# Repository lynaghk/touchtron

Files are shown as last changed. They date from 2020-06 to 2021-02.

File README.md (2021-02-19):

# Touchtron

Misc. experiments with Rust + USB, Kevin making a touchpad.

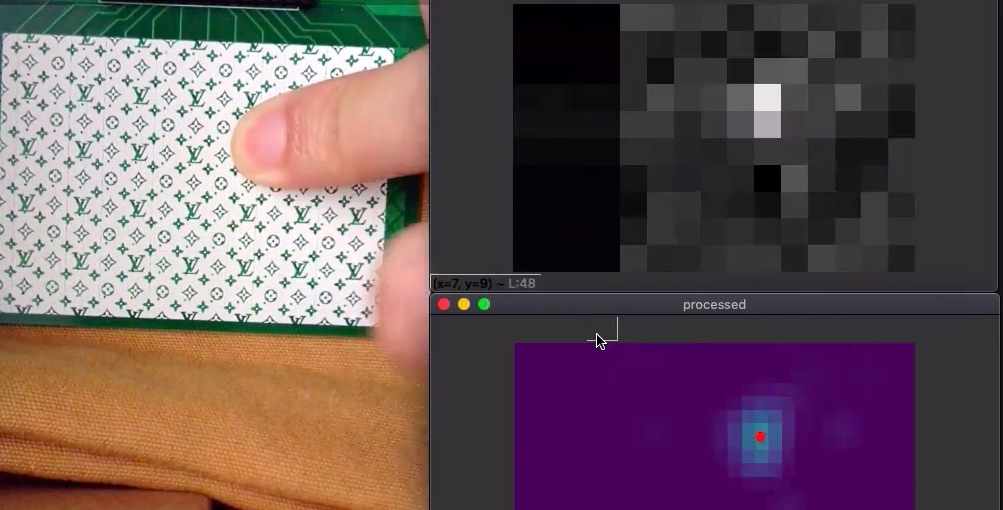
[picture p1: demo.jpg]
A finger on a touchpad; data analysis windows


See [background + video demo](https://kevinlynagh.com/touchpad/).

The [firmware-f0](firmware-f0/) is the fully-baked code running on the PCB ([schematic PDF](pcb/submitted_2020_05_26/touchtron.pdf)).

This was a personal research project that I'm sharing in case it's helpful for others playing with touchpads, embedded Rust, etc.

## MacOS Setup 

```
#for stm32f0 (kevin custom board)
rustup target add thumbv6m-none-eabi 

#for stm32f1 (blue pill board)
rustup target add thumbv7m-none-eabi

pip install numpy matplotlib scipy opencv-python

pip install pyusb
brew install libusb 
```

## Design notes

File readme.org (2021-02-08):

# Touchtron

Misc. experiments with Rust + USB, Kevin making a touchpad.

* MacOS Setup 

#for stm32f0 (kevin custom board)
rustup target add thumbv6m-none-eabi 

#for stm32f1 (blue pill board)
rustup target add thumbv7m-none-eabi

pip install numpy matplotlib scipy opencv-python

pip install pyusb
brew install libusb 

MIDI stuff:
virtual keyboard for generating events: https://flit.github.io/projects/midikeys/
monitoring MIDI events on the system: https://www.snoize.com/MIDIMonitor/

* misc research / notes
https://jan.rychter.com/fingerworks-touchstream-kbd

https://bill.harding.blog/tag/touchpad/

clever in software debouncing: https://github.com/dbrgn/debouncr/
** lcsc stm32 parts with lots of channels
| part          | adcs |     CHs | basic? | pins | cost | note                        |
| STM32F303RCT6 |    4 | 22 real |        |   64 | 2.94 |                             |
| STM32F103VBT6 |    2 |      16 | x      |  100 | 1.99 |                             |
| STM32L073V8T6 |    1 |      16 |        |  100 | 1.96 | crystalless usb             |
| STM32F407VGT6 |    3 |     ... |        |      | 4.33 | adcs share same 16 channels |
| STM32L151C8T6 |    1 |      24 | x      |   48 | 1.85 |                             |
| STM32L152RBT6 |    1 |      24 |        |   64 | 2.90 |                             |
| STM32F030C8T6 |    1 |      16 | x      |   48 | 0.79 | no usb                      |
| STM32G031C6T6 |    1 |      16 |        |   48 | 1.68 |                             |
** other ways to get more rows/columns:

https://electronics.stackexchange.com/questions/293809/connecting-multiple-signals-to-adc

CD4051B is $0.20 JLC part that demuxes 8 channels to 1. filed under "4000" series rather than "multiplexers" = (
74HC4051D $0.12e JLC 8-to-1 demux

need op-amp to buffer high-impedence touchpad sensor signal?

STM32F070F6 

$0.0015/joint

** Mac raw gesture data
from https://ia801404.us.archive.org/15/items/2009-03-28-steike-code-macbook-multitouch/2009-03-28%20%28archived%202014-06-17%29%20-%20steike%20macbook%20multitouch.html
via Vivek

Here's code to read the raw gesture data from a MacBook trackpad.

[Update: if you're on a MacBook with Java enabled, you can try the demo applet]

If you use this to make something fun, please let me know and I'll post it here...

Notes about the fields of the Finger struct:

identifier
    Persistent identifier for each touch -- each "finger" may move around the Fingers[] array, but this will remain the same. 
normalized.pos.x
    Current position, from [0..1] 
size
    Close to zero if you're barely touching the touch pad 
angle, majorAxis, minorAxis
    Describes the ellipsoid of your finger. Yes, you can track rotation of a single finger! 

#include <math.h>
#include <unistd.h>
#include <CoreFoundation/CoreFoundation.h>

typedef struct { float x,y; } mtPoint;
typedef struct { mtPoint pos,vel; } mtReadout;

typedef struct {
  int frame;
  double timestamp;
  int identifier, state, foo3, foo4;
  mtReadout normalized;
  float size;
  int zero1;
  float angle, majorAxis, minorAxis; // ellipsoid
  mtReadout mm;
  int zero2[2];
  float unk2;
} Finger;

typedef void *MTDeviceRef;
typedef int (*MTContactCallbackFunction)(int,Finger*,int,double,int);

MTDeviceRef MTDeviceCreateDefault();
void MTRegisterContactFrameCallback(MTDeviceRef, MTContactCallbackFunction);
void MTDeviceStart(MTDeviceRef, int); // thanks comex

int callback(int device, Finger *data, int nFingers, double timestamp, int frame) {
  for (int i=0; i<nFingers; i++) {
    Finger *f = &data[i];
    printf("Frame %7d: Angle %6.2f, ellipse %6.3f x%6.3f; "
    	   "position (%6.3f,%6.3f) vel (%6.3f,%6.3f) "
    	   "ID %d, state %d [%d %d?] size %6.3f, %6.3f?\n",
	   f->frame,
	   f->angle * 90 / atan2(1,0),
	   f->majorAxis,
	   f->minorAxis,
	   f->normalized.pos.x,
	   f->normalized.pos.y,
	   f->normalized.vel.x,
	   f->normalized.vel.y,
	   f->identifier, f->state, f->foo3, f->foo4,
	   f->size, f->unk2);
  }
  printf("\n");
  return 0;
}

int main() {
  MTDeviceRef dev = MTDeviceCreateDefault();
  MTRegisterContactFrameCallback(dev, callback);
  MTDeviceStart(dev, 0);
  printf("Ctrl-C to abort\n");
  sleep(-1);
  return 0;
}

run: test
	./test
test: test.m
	gcc -F/System/Library/PrivateFrameworks -framework MultitouchSupport $^ -o $@ -std=c99

Comments
Could you please explain how you go about compiling this code. I tried including the MultitouchSupport framework under PrivateFrameworks and I get "ld: framework not found MultitouchSupport"
— Al 2009-05-27
[Ah, I hadn't tried compiling it in Xcode. It appears to be silently prepending all paths with /Developer/SDKs/MacOS10.xxx/. You need to change the 'Base SDK' setting (under Project settings) from 'MacOS 10.whatever' to 'Current OS'.]
Excelletn stuff. Al, the sendo text is a make file, just put it into 'Makefile' in the same dir and type make. I am wrapping the code in a Java Wrapper, but im only geting the MT debug init message, not any MT events. I guess its somethine todo with threading (e.g. main thread) and perhaps how the java binary is (or not) dynamically binding with the Framework(s). I'm really not sure asthis is my 1st trip into native MacOS system dev/integration... (but im well seasoned elsewhere :)
— Wayne 2009-05-27
Excellent! We just built an external for MaxMSP around your code. We'd like to release it under the GNU GPL 2.0, if that is fine by you? [binary / source]
— Max & Michael 2009-06-02
[Brilliant! Max/MSP looks awesome; I'll have to play with it as soon as I'm done moving.]
Hi, Greetings from the maker of the multitouch Fingerworks NumPad Max/MSP external I salute you! The circle is now complete.
— jusu 2009-06-08
Great stuff! The only problem is that when I play with the gestures, I tend to trigger Expose. Any idea how to deactivate it (at least the three- and four-finger gestures that aren't really all that useful to begin with)?
— Robert 2009-07-02
[For testing purposes, I just used killall -STOP Dock. This also disables Cmd-Tab and other system hotkeys; killall -CONT Dock to bring it back.]
Cool!

btw, can I use the code inside my own project? I'm gonna release the project under GPL because I use another library that uses GPL. By doing so, it means, I also release your code under GPL.

I make a TUIO wrapper over your code. So the multi-touch events from the touchpad will be forwarded as TUIO messages. These later can be used by any TUIO-enabled multi-touch application.
— Anonymous 2009-08-08
Very cool stuff! I build a TUIO wrapper around your code (http://github.com/fajran/tongseng/tree/master). In case you don't know, TUIO is a protocol that is usually used to create a multitouch application. More information here http://www.tuio.org/
— Fajran 2009-08-15
To get this to work on Snow Leopard/64-bit/in a more complicated program, I had to change MTDeviceRef to a long and add a second int argument to MTDeviceStart; otherwise, I would get crashes and/or no events.
— comex 2009-08-30
[I have updated the code. Thanks!]
Perhaps I am too foolish or new to make this work, but on Snow Leopard 10.6.1 when I put the source in 'test.m' and have a Makefile it makes, but I get a segmentation fault when I run it. fprintf tells me that the fault happens during

MTRegisterContactFrameCallback(dev, callback);

I have also tried copying the MultitouchSupport.framework folder in to the folder I'm working in, and to no avail.

Is this different in 10.6 then? Am I missing something?
— Jonathan 2009-09-21
[This was preemptively answered by comex, but his comment was stuck in the 
* Log
To try:

+ paper's lowest SNR = 57 +/- 20; single touch SNR around 70 +/- 10; ratio of 15 is min required.
+ "We observed that thicker top insulators (more than 400 um) will render the interface unusable." (soldermask thickness ~ 25 um; silkscreen is similar.)

** 2020 June 24 measurement

Using Hackerspace's Hantek DSO8060 portable scope to measure touchpad.

Measuring output ch 6, input ch 4

4ms period for a single pin --- this is the column scan.
Zooming in it reads 10MHz signal for the PWM.

PWM peak to peak voltage is 1.9V
Untouched 220mV
Touched 0.9--1.1V but the signal floats all over the place (varying DC offset)
However, it's clearly coupled to the PWM output signal

At period = 48 (1MHz):

PWM peak to peak is 3V
untouched 260mV
touched 0.8--1V, also floating everywhere. why?

hmm, maybe the floating was scope probe error.
Going back to 9.6MHz signal (period = 4; must be an extra cycle in there somewhere.) I see

1.9 PWM peak to peak
220 mV untouched
550 mV light touch

sometimes the floor wiggles around, other times I can cause big amplitude increase from coupling but the floor stays constant.
I think the floor movement is noise from my finger
maybe I need a high pass filter to get rid of it?

** 2020 June 23 Python analysis

Matplotlib code struggles to update heatmap quickly.
Perf timing in code suggests it can run at 160 FPS but it's obviously not running that fast.
Scaling the window makes it even laggier.

Tried upgrading to python3.8, changing backend to qt5. no dice.

** 2020 June 22 ADC overrun
I keep getting overrun errors from the ADC, even when the interrupt just reads the register and does nothing else.
Maybe this read is getting optimized away?
Nah, must be timing because even if the interrupt runs only:

    self.adc.rb.isr.modify(|_, w| w.eoc().clear());

I still get overrun errors
This doesn't make sense, is the ADC really sampling that fast?

----

with no pwm signal, noise is around 8--9.
50--90 with a finger.
With a single PWM, noise is around 80--100.

** 2020 June 21 Manual ADC usage

ADC can be set to scan through all channels in order.
Lets just do this continously, collecting values in a rolling buffer or something.
Then when USB polls we can send all collected data to the host

enable channels in ADC_CHSELR
ADC_CFGR1.cont = 1

set EOCIE flag so interrupt is generated after each sample taken
clear EOC flag and transfer result to new buffer

watch OVR flag for overrun. this shouldn't happen in normal operation if interrupt handler is fast enough.

We could also setup DMA to read all rows, that'd be cool: (Set this after calibration phase:  ADC_CFGR1.DMAEN = 1)
Eh, lets try that later.
We should have plenty of time to use regular interrupts

----

Man, trying to write register stuff using rust SVD is a huge pain.
Autocomplete doesn't work, lots of fiddly options about what's a method, what's a register, etc.
Really thinking Rust and fancy types aren't worth it; they get in the way a lot, but I ALSO still end up having to cast to untyped ints and duplicate definitions to get things to work.

Would be interesting to play with a mini-language / constraint system designed explicitly for microcontroller programming.

** 2020 June 20 USB speed test

USB full speed => 64 bytes/frame.
Max polling interval = every frame (1 frame/ms).
151 u16 vals = 302 bytes => theoretical top speed of 1 report every 5ms.

According to my python code, I'm getting about 160--180 reads/sec (5.5 -- 6.3ms). Cool.

So how come when I report synthetic data with a single filled square moving through the index, it takes ~5 seconds to go through all 150 cells?

Maybe the delay is on the rendering side?

Ah, yeah. If I just read 150 frames without trying to numpy, it takes 751ms, which is almost exactly 5*150.
Nice when computers actually keep good time.

So how come I get flickering ADC measurement?

---

with no touches, noise readings are within 100--200. a touch goes up to around 300.
Maybe the flicker is because the sample is taken entirely within PWM "off" time?
Doesn't seem possible if period is 4 ticks.

Okay, even connecting an ADC pin directly to a PWM output, the columns "flicker".
But when connecting to a 3.3V rail, the entire ADC row is lit as expected.
So maybe I don't fully understand my PWM signal?
Perhaps I need to just set the ADC to go in "low frequency mode".
Or just do that in software by averaging multiple readings.

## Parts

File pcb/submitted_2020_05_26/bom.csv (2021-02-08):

Comment | Designator | Footprint | LCSC Part #
Ferrite_Bead | FB1 | 805 | C1015
10n | C3 | 402 | C15195
100n | C4,C5,C7,C10 | 402 | C1525
330 | R12,R13,R14 | 805 | C17630
Green LED | D3 | 805 | C2297
4.7u | C8,C9 | 402 | C23733
100k | R1,R2,R3,R4,R5,R6,R7,R8,R9,R11 | 402 | C25741
5.1k | R10 | 402 | C25905
TS-1187A-C-D-B | SW1,SW2,SW3,SW4 | SMD-SW-4_5.1x5.1x2.0 | C318888
White LED | D1,D2 | 805 | C34499
1u | C1,C2,C6 | 402 | C52923
XC6206P332MR | U1 | SOT-23-3L | C5446
USBLC6-2SC6 | U2 | SOT-23-6L | C7519
STM32F072CBT6 | U3 | LQFP-48_7.0x7.0x0.5P | C81720

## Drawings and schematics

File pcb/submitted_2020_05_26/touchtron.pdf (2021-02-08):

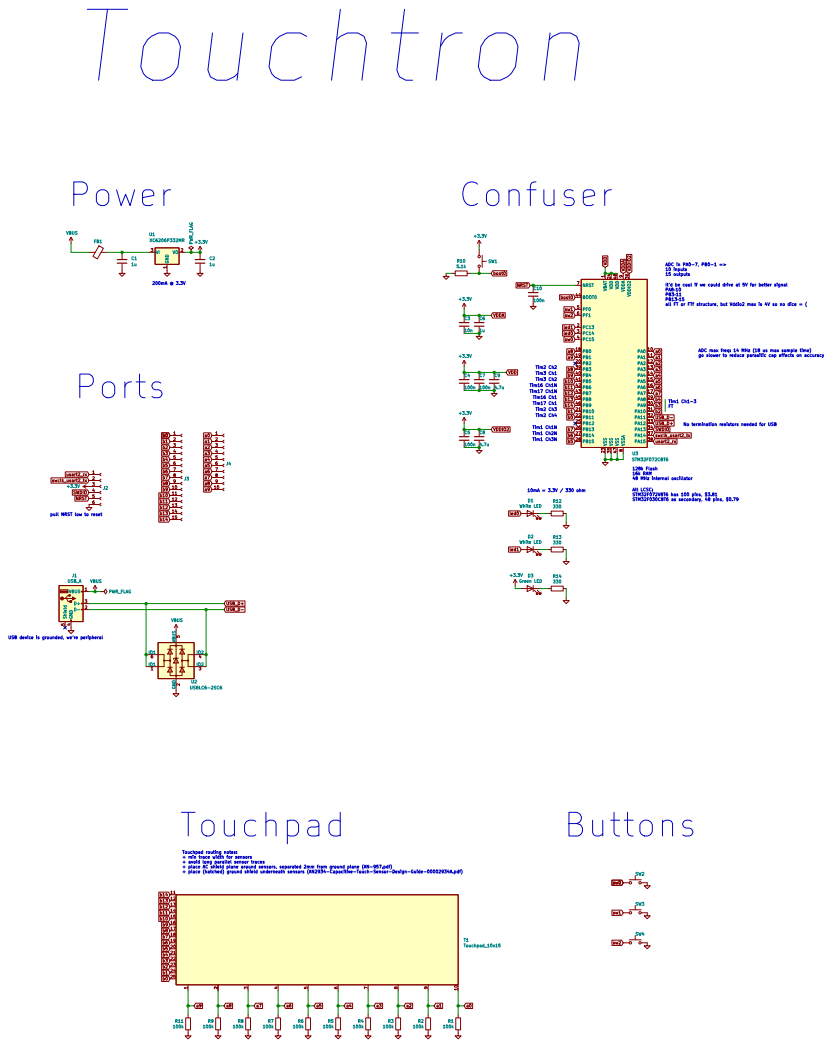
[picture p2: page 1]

48 MHz internal oscillator Confuser
15 outputs Alt LCSC: STM32F072V8T6 has 100 pins, $3.81
a9 NRST

go slower to reduce parasitic cap effects on accuracy ADC in PA0-7, PB0-1 => 10 inputs

1 PA0 10 PA1 11 PA2 12 PA3 13 PA4 14 PA5 15 PA6 16 PA7 17 PB0 18 PB1 19 PC13 2 PB2 20 PB10 21 PB11 22 VSS 23 VDD 24 PB12 25 PB13 26 PB14 27 PB15 28 PA8 29 PC14 3 PA9 30 PA10 31 PA11 32 PA12 33 PA13 34 VSS 35 VDDIO2 36 PA14 37 PA15 38 PB3 39 PC15 4 PB4 40 PB5 41 PB6 42 PB7 43 BOOT0 44 PB8 45 PB9 46 VSS 47 VDD 48 PF0 5 PF1 6 NRST 7 VSSA

Itd be cool if we could drive at 5V for better signal PA810 PB311 PB1315

all FT or FTf structure, but Vddio2 max is 4V so no dice = ( 10mA = 3.3V / 330 ohm

ADC max freq: 14 MHz (18 us max sample time)

STM32F030C8T6 as secondary, 48 pins, $0.79 Tim1 Ch1-3 FT

No termination resistors needed for USB

USB device is grounded, were peripheral

Touchpad routing notes: + min trace width for sensors + avoid long parallel sensor traces

+ place AC shield plane around sensors, separated 2mm from ground plane (AN-957.pdf)
+ place (hatched) ground shield underneath sensors (AN2934-Capacitive-Touch-Sensor-Design-Guide-00002934A.pdf)

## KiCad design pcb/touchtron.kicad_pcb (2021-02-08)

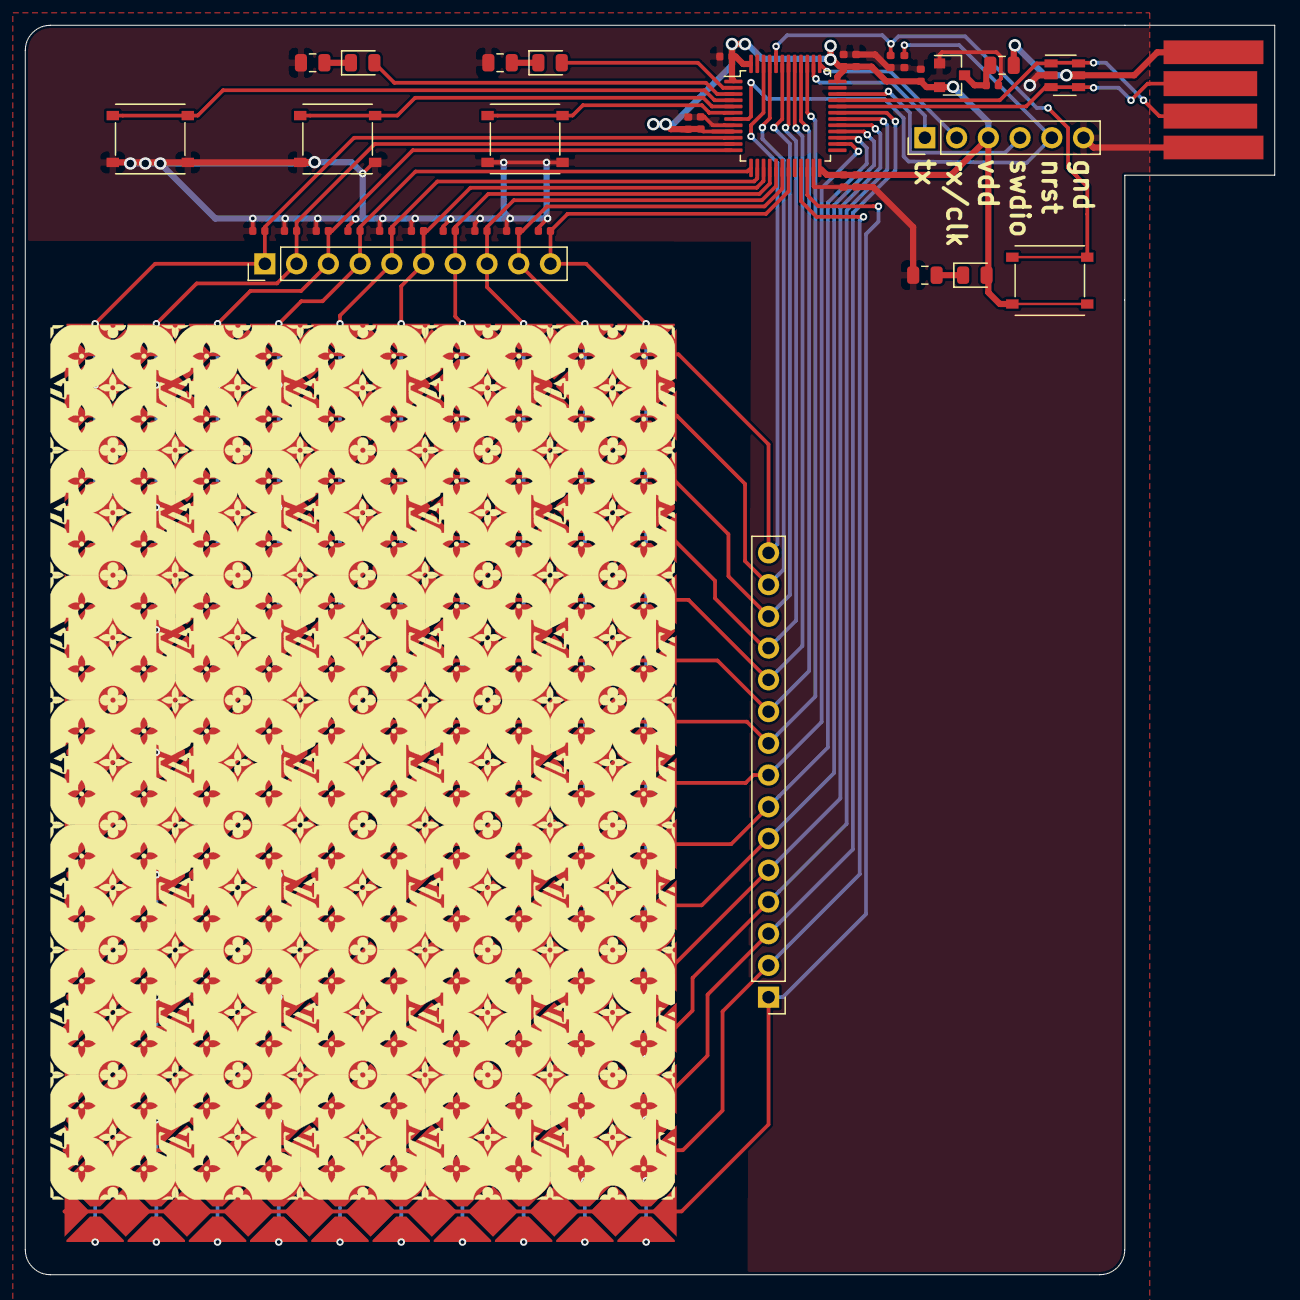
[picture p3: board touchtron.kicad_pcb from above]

Board: 2 copper layers, 100.0 x 100.0 mm, 40 parts (0 on the bottom side), 44 nets.

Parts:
C1, C2, C6: 1u; C_0402_1005Metric
C3: 10n; C_0402_1005Metric
C4, C5, C7, C10: 100n; C_0402_1005Metric
C8, C9: 4.7u; C_0402_1005Metric
D1, D2: White LED; LED_0805_2012Metric
D3: Green LED; LED_0805_2012Metric
FB1: Ferrite_Bead; C_0805_2012Metric
J1: USB_A; usb_a_edge_connector
J2: Conn_01x06_Female; PinHeader_1x06_P2.54mm_Vertical
J3: Conn_01x15_Female; PinHeader_1x15_P2.54mm_Vertical
J4: Conn_01x10_Female; PinHeader_1x10_P2.54mm_Vertical
R1, R2, R3, R4, R5, R6, R7, R8, R9, R11: 100k; R_0402_1005Metric
R10: 5.1k; R_0402_1005Metric
R12, R13, R14: 330; R_0805_2012Metric
SW1, SW2, SW3, SW4: TS-1187A-C-D-B; TS-1187A
T1: Touchpad_10x15; touchpad_49_10_15
U1: XC6206P332MR; SOT-23
U2: USBLC6-2SC6; SOT-23-6
U3: STM32F072CBT6; LQFP-48_7x7mm_P0.5mm

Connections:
GND: C1.2, C2.2, C3.2, C4.2, C5.2, C6.2, C7.2, C8.2, C9.2, C10.2, J1.4, J2.6, R1.2, R2.2, R3.2, R4.2, R5.2, R6.2, R7.2, R8.2, R9.2, R10.2, R11.2, R12.1, R13.1, R14.1, SW2.2, SW3.2, SW4.2, U1.1, U2.2, U3.8, U3.23, U3.35, U3.47
NRST: C10.1, J2.5, U3.7
unnamed: C1.1, FB1.1, U1.3
unnamed: D1.1, R12.2
unnamed: D2.1, R13.2
unnamed: D3.1, R14.2
SWDIO: J2.4, U3.34
USB_D+: J1.3, U2.1, U2.6, U3.33
USB_D-: J1.2, U2.3, U2.4, U3.32
VBUS: FB1.2, J1.1, U2.5
VDD: C2.1, C3.1, C4.1, C5.1, C6.1, C7.1, C8.1, C9.1, D3.2, J2.3, SW1.1, U1.2, U3.1, U3.9, U3.24, U3.36, U3.48
a0: J4.1, R1.1, T1.10, U3.10
a1: J4.2, R2.1, T1.9, U3.11
a2: J4.3, R3.1, T1.8, U3.12
a3: J4.4, R4.1, T1.7, U3.13
a4: J4.5, R5.1, T1.6, U3.14
a5: J4.6, R6.1, T1.5, U3.15
a6: J4.7, R7.1, T1.4, U3.16
a7: J4.8, R8.1, T1.3, U3.17
a8: J4.9, R9.1, T1.2, U3.18
a9: J4.10, R11.1, T1.1, U3.19
b0: J3.1, T1.25, U3.22
b1: J3.2, T1.24, U3.21
b2: J3.3, T1.23, U3.31
b3: J3.4, T1.22, U3.30
b4: J3.5, T1.21, U3.29
b5: J3.6, T1.20, U3.28
b6: J3.7, T1.19, U3.27
b7: J3.8, T1.18, U3.26
b8: J3.9, T1.17, U3.39
b9: J3.10, T1.16, U3.40
b10: J3.11, T1.15, U3.41
b11: J3.12, T1.14, U3.42
b12: J3.13, T1.13, U3.43
b13: J3.14, T1.12, U3.45
b14: J3.15, T1.11, U3.46
boot0: R10.1, SW1.2, U3.44
led0: D1.2, U3.3
led1: D2.2, U3.2
sw0: SW2.1, U3.4
sw1: SW3.1, U3.5
sw2: SW4.1, U3.6
swclk_usart2_tx: J2.2, U3.37
usart2_rx: J2.1, U3.38

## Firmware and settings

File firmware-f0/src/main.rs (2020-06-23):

#![no_std]
#![no_main]

extern crate panic_semihosting;
use cortex_m::asm::{bkpt, delay, wfi};
use stm32_usbd::UsbBus;
use stm32f0xx_hal::{
    gpio,
    gpio::{
        gpioa::*, gpiob::*, gpioc::*, gpiof::*, Alternate, Analog, Output, PushPull, AF0, AF1, AF2,
        AF3, AF4, AF5, AF6, AF7,
    },
    prelude::*,
    rcc::Rcc,
    stm32 as hw,
    stm32::{GPIOA, GPIOB, TIM1, TIM16, TIM17, TIM2, TIM3},
    usb::UsbBusType,
};

use usb_device::prelude::*;

use rtfm::app;

mod adc;
mod reporter;
use adc::Adc;

const N: usize = 15;
const M: usize = 10;
const TOUCH_DATA_LEN: usize = 1 + M * N; //one extra val at start for the PWM period

const INITIAL_PERIOD: u16 = 4; //Multitouch paper suggests peak SNR at 10 MHz freq

#[derive(Copy, Clone)]
pub struct TouchData {
    pub inner: [u16; TOUCH_DATA_LEN],
}

impl TouchData {
    fn new() -> TouchData {
        TouchData {
            inner: [0u16; TOUCH_DATA_LEN],
        }
    }

    fn clear(&mut self) {
        for idx in 0..TOUCH_DATA_LEN {
            self.inner[idx] = 0;
        }
    }

    fn take(&mut self) -> Self {
        let copy = self.clone();
        self.clear();
        copy
    }

    fn add(&mut self, other: &TouchData) {
        self.inner[0] += 1;
        for idx in 1..TOUCH_DATA_LEN {
            self.inner[idx] += other.inner[idx];
        }
    }
}

//TODO: is this the best way to get array of u16 into a slice of u8?
impl AsRef<[u8]> for TouchData {
    #[inline]
    fn as_ref(&self) -> &[u8] {
        unsafe {
            core::slice::from_raw_parts_mut(self.inner.as_ptr() as *mut u8, self.inner.len() * 2)
        }
    }
}

//TODO: macro to generate match by "iterating" over enum?
//TODO: HAL turns ADC on/off between each read; probably want to use highest speed "continuous scanning" mode from hardware.
type TouchpadInputPins = (
    PA0<Analog>,
    PA1<Analog>,
    PA2<Analog>,
    PA3<Analog>,
    PA4<Analog>,
    PA5<Analog>,
    PA6<Analog>,
    PA7<Analog>,
    PB0<Analog>,
    PB1<Analog>,
);

macro_rules! PwmOutput {
    ($O: ident, $gpioX: ident, $moderI: ident, $pin: ty, $TIM: ident, $ccXe: ident) => {
        struct $O($pin);

        impl $O {
            fn on(&self) {
                //enable pwm channel
                unsafe { &(*$TIM::ptr()) }
                    .ccer
                    .modify(|_, w| w.$ccXe().set_bit());
                //make pin alternate fn
                unsafe { &(*$gpioX::ptr()) }
                    .moder
                    .write(|w| w.$moderI().alternate());
            }
            fn off(&self) {
                unsafe { &(*$TIM::ptr()) }
                    .ccer
                    .modify(|_, w| w.$ccXe().clear_bit());

                //make pin output (defaults to low)
                unsafe { &(*$gpioX::ptr()) }
                    .moder
                    .write(|w| w.$moderI().output());
            }
        }
    };
}

//TODO: how much code does this generate?
PwmOutput!(B0, GPIOB, moder11, PB11<Alternate<AF2>>, TIM2, cc4e);
PwmOutput!(B1, GPIOB, moder10, PB10<Alternate<AF2>>, TIM2, cc3e);
PwmOutput!(B2, GPIOA, moder10, PA10<Alternate<AF2>>, TIM1, cc3e);
PwmOutput!(B3, GPIOA, moder9, PA9<Alternate<AF2>>, TIM1, cc2e);
PwmOutput!(B4, GPIOA, moder8, PA8<Alternate<AF2>>, TIM1, cc1e);
PwmOutput!(B5, GPIOB, moder15, PB15<Alternate<AF2>>, TIM1, cc3ne);
PwmOutput!(B6, GPIOB, moder14, PB14<Alternate<AF2>>, TIM1, cc2ne);
PwmOutput!(B7, GPIOB, moder13, PB13<Alternate<AF2>>, TIM1, cc1ne);
PwmOutput!(B8, GPIOB, moder3, PB3<Alternate<AF2>>, TIM2, cc2e);
PwmOutput!(B9, GPIOB, moder4, PB4<Alternate<AF1>>, TIM3, cc1e);
PwmOutput!(B10, GPIOB, moder5, PB5<Alternate<AF1>>, TIM3, cc2e);
PwmOutput!(B11, GPIOB, moder6, PB6<Alternate<AF2>>, TIM16, cc1e);
PwmOutput!(B12, GPIOB, moder7, PB7<Alternate<AF2>>, TIM17, cc1e);
PwmOutput!(B13, GPIOB, moder8, PB8<Alternate<AF2>>, TIM16, cc1e);
PwmOutput!(B14, GPIOB, moder9, PB9<Alternate<AF2>>, TIM17, cc1e);

type TouchpadOutputPins = (
    B0,  //tim2ch4
    B1,  //tim2ch3
    B2,  //tim1ch3
    B3,  //tim1ch2
    B4,  //tim1ch1
    B5,  //tim1ch3n
    B6,  //tim1ch2n
    B7,  //tim1ch1n
    B8,  //tim2ch2
    B9,  //tim3ch1
    B10, //tim3ch2
    B11, //tim16ch1n
    B12, //tim17ch1n
    B13, //tim16ch1
    B14, //tim17ch1
);

pub struct Touchpad {
    adc: Adc,
    timers: (TIM1, TIM2, TIM3, TIM16, TIM17),
    input_pins: TouchpadInputPins,
    output_pins: TouchpadOutputPins,
    period: u16,
    in_progress: TouchData,
    current_row: usize,
    current_col: usize,
}

impl Touchpad {
    fn on(&mut self, idx: usize) {
        match idx {
            0 => self.output_pins.0.on(),
            1 => self.output_pins.1.on(),
            2 => self.output_pins.2.on(),
            3 => self.output_pins.3.on(),
            4 => self.output_pins.4.on(),
            5 => self.output_pins.5.on(),
            6 => self.output_pins.6.on(),
            7 => self.output_pins.7.on(),
            8 => self.output_pins.8.on(),
            9 => self.output_pins.9.on(),
            10 => self.output_pins.10.on(),
            11 => self.output_pins.11.on(),
            12 => self.output_pins.12.on(),
            13 => self.output_pins.13.on(),
            14 => self.output_pins.14.on(),
            _ => {}
        }
    }
    fn off(&mut self, idx: usize) {
        match idx {
            0 => self.output_pins.0.off(),
            1 => self.output_pins.1.off(),
            2 => self.output_pins.2.off(),
            3 => self.output_pins.3.off(),
            4 => self.output_pins.4.off(),
            5 => self.output_pins.5.off(),
            6 => self.output_pins.6.off(),
            7 => self.output_pins.7.off(),
            8 => self.output_pins.8.off(),
            9 => self.output_pins.9.off(),
            10 => self.output_pins.10.off(),
            11 => self.output_pins.11.off(),
            12 => self.output_pins.12.off(),
            13 => self.output_pins.13.off(),
            14 => self.output_pins.14.off(),
            _ => {}
        }
    }

    pub fn adc_interrupt(&mut self) -> Option<TouchData> {
        let status = self.adc.rb.isr.read();
        //self.adc.rb.isr.modify(|_, w| w.eoc().clear());
        // //cortex_m_semihosting::hprintln!("{:#018b}", status.bits()).unwrap();
        if status.ovr().is_overrun() {
            panic!("overrun");
        }
        if status.eoc().is_complete() {
            //reading the register will clear the eoc flag
            self.next_row(self.adc.rb.dr.read().bits() as u16)
        } else {
            None
        }
    }

    fn next_row(&mut self, reading: u16) -> Option<TouchData> {
        self.in_progress.inner[1 + N * self.current_row + self.current_col] = reading;
        self.current_row = (self.current_row + 1) % M;
        //        delay(200);
        self.adc.start(self.current_row as u8);

        if 0 == self.current_row {
            self.next_column()
        } else {
            None
        }
    }

    fn next_column(&mut self) -> Option<TouchData> {
        self.off(self.current_col);
        self.current_col = (self.current_col + 1) % N;
        self.on(self.current_col);

        if 0 == self.current_col {
            Some(self.in_progress.take())
        } else {
            None
        }
    }

    pub fn set_period(&mut self, period: u16) {
        self.period = period;
        self.timers.0.set_period(period);
        self.timers.1.set_period(period);
        self.timers.2.set_period(period);
    }
}

trait PWM {
    fn start(&self, rcc: &mut hw::RCC);
    fn set_period(&self, ticks: u16);
}

macro_rules! impl_pwm {
    ($TIM:ident, $tim:ident, $timXen:ident, $apbenr:ident) => {
        impl PWM for $TIM {
            fn start(&self, rcc: &mut hw::RCC) {
                //enable
                rcc.$apbenr.modify(|_, w| w.$timXen().set_bit());

                self.ccmr1_output().modify(|_, w| {
                    //pwm mode 1
                    w.oc1m().bits(0b110);
                    w.oc2m().bits(0b110);
                    //preload
                    w.oc1pe().set_bit();
                    w.oc2pe().set_bit();
                    w
                });

                self.ccmr2_output().modify(|_, w| {
                    //pwm mode 1
                    w.oc3m().bits(0b110);
                    w.oc4m().bits(0b110);

                    //preload
                    w.oc3pe().set_bit();
                    w.oc4pe().set_bit();
                    w
                });

                //auto reload preload enabled
                self.cr1.modify(|_, w| w.arpe().set_bit());

                self.set_period(INITIAL_PERIOD);

                //finally, start timer
                self.cr1.modify(|_, w| w.cen().set_bit());
            }

            fn set_period(&self, ticks: u16) {
                self.arr.modify(|_, w| w.arr().bits(ticks.into()));

                //set 50% duty cycle
                unsafe {
                    self.ccr1.write(|w| w.bits((ticks / 2).into()));
                    self.ccr2.write(|w| w.bits((ticks / 2).into()));
                    self.ccr3.write(|w| w.bits((ticks / 2).into()));
                    self.ccr4.write(|w| w.bits((ticks / 2).into()));

                    // self.ccr1.write(|w| w.bits(1));
                    // self.ccr2.write(|w| w.bits(1));
                    // self.ccr1.write(|w| w.bits(1));
                    // self.ccr4.write(|w| w.bits(1));
                }

                //"As the preload registers are transferred to the shadow registers only when an update event occurs, before starting the counter, you have to initialize all the registers by setting the UG bit in the TIMx_EGR register."
                self.egr.write(|w| w.ug().update());
            }
        }
    };
}

type Led0 = PC14<Output<PushPull>>;
type Led1 = PC13<Output<PushPull>>;

#[app(device = hw)]
const APP: () = {
    struct Resources {
        leds: (Led0, Led1),
        exti: hw::EXTI,
        usb_device: UsbDevice<'static, UsbBusType>,
        reporter: reporter::Reporter<'static, UsbBusType, TouchData>,
        touchpad: Touchpad,
    }

    #[init]
    fn init(_cx: init::Context) -> init::LateResources {
        // init() is already run with interrupts disabled,
        // but we need a CriticalSection to pass to some stm32f0xx_hal methods
        cortex_m::interrupt::free(move |cs| {
            let mut dp = hw::Peripherals::take().unwrap();

            // enable SYSCFG clock
            dp.RCC.apb2enr.modify(|_, w| w.syscfgen().enabled());

            let mut rcc = dp
                .RCC
                .configure()
                .hsi48()
                .enable_crs(dp.CRS)
                .sysclk(48.mhz())
                //TODO: should this be 48 too?
                .pclk(48.mhz())
                .freeze(&mut dp.FLASH);

            //just make all gpio ports high speed
            unsafe {
                dp.GPIOA.ospeedr.write(|w| w.bits(0xffff));
                dp.GPIOB.ospeedr.write(|w| w.bits(0xffff));
            }

            let gpioa = dp.GPIOA.split(&mut rcc);
            let gpiob = dp.GPIOB.split(&mut rcc);
            let gpioc = dp.GPIOC.split(&mut rcc);
            let gpiof = dp.GPIOF.split(&mut rcc);
            let syscfg = dp.SYSCFG;
            let exti = dp.EXTI;

            let switch0 = gpioc.pc15.into_pull_up_input(cs);
            let switch1 = gpiof.pf0.into_pull_up_input(cs);
            let switch2 = gpiof.pf1.into_pull_up_input(cs);

            let mut led0 = gpioc.pc14.into_push_pull_output(cs);
            let mut led1 = gpioc.pc13.into_push_pull_output(cs);
            // led0.set_high().unwrap();
            // led1.set_high().unwrap();

            // Enable external interrupt EXTI0 for PA0
            syscfg.exticr1.write(|w| w.exti0().pa0());

            // Set interrupt request mask for line 0
            exti.imr.modify(|_, w| w.mr0().set_bit());

            // Set interrupt falling trigger for line 0
            exti.ftsr.modify(|_, w| w.tr0().set_bit());

            // UsbDevice take refs to usb_bus but outlive init()
            // so usb_bus must be owned with static lifetime
            // see https://github.com/Rahix/shared-bus/issues/4#issuecomment-503512441
            static mut USB_BUS: Option<usb_device::bus::UsbBusAllocator<UsbBusType>> = None;

            //TODO: how the hell am I supposed to use this method? it's public, but the ::new constructor on UsbBus doesn't return the Bus, it wraps it in an allocator! There's a freeze method on the allocator that returns the bus, but it's only public within the usb crate. ugh.
            //UsbBusType::force_reenumeration(&dp.USB, || {});

            let usb_bus = unsafe {
                USB_BUS = Some(UsbBus::new(stm32f0xx_hal::usb::Peripheral {
                    usb: dp.USB,
                    pin_dm: gpioa.pa11,
                    pin_dp: gpioa.pa12,
                }));
                USB_BUS.as_ref().unwrap()
            };

            //turn on PWM timers

            impl_pwm!(TIM1, tim1, tim1en, apb2enr);
            impl_pwm!(TIM2, tim2, tim2en, apb1enr);
            impl_pwm!(TIM3, tim3, tim3en, apb1enr);
            // impl_pwm!(TIM16, tim16, tim16en, apb2enr);
            // impl_pwm!(TIM17, tim17, tim17en, apb2enr);

            let mut rcc_raw = unsafe { hw::Peripherals::steal().RCC }; //HAL consumed this...but I want it.

            dp.TIM1.start(&mut rcc_raw);
            //TIM1 has special "main output enable" bit that must be set before it emits signal
            dp.TIM1.bdtr.modify(|_, w| {
                w.moe().set_bit();
                w.ossr().set_bit();
                w
            });

            dp.TIM2.start(&mut rcc_raw);
            dp.TIM3.start(&mut rcc_raw);
            // dp.TIM16.start(&mut rcc_raw);
            // dp.TIM17.start(&mut rcc_raw);

            let mut touchpad = Touchpad {
                current_row: 0,
                current_col: 0,
                period: INITIAL_PERIOD,
                in_progress: TouchData::new(),
                timers: (dp.TIM1, dp.TIM2, dp.TIM3, dp.TIM16, dp.TIM17),
                adc: Adc::new(dp.ADC, &mut rcc_raw),
                input_pins: (
                    gpioa.pa0.into_analog(cs),
                    gpioa.pa1.into_analog(cs),
                    gpioa.pa2.into_analog(cs),
                    gpioa.pa3.into_analog(cs),
                    gpioa.pa4.into_analog(cs),
                    gpioa.pa5.into_analog(cs),
                    gpioa.pa6.into_analog(cs),
                    gpioa.pa7.into_analog(cs),
                    gpiob.pb0.into_analog(cs),
                    gpiob.pb1.into_analog(cs),
                ),
                output_pins: (
                    B0(gpiob.pb11.into_alternate_af2(cs)),
                    B1(gpiob.pb10.into_alternate_af2(cs)),
                    B2(gpioa.pa10.into_alternate_af2(cs)),
                    B3(gpioa.pa9.into_alternate_af2(cs)),
                    B4(gpioa.pa8.into_alternate_af2(cs)),
                    B5(gpiob.pb15.into_alternate_af2(cs)),
                    B6(gpiob.pb14.into_alternate_af2(cs)),
                    B7(gpiob.pb13.into_alternate_af2(cs)),
                    B8(gpiob.pb3.into_alternate_af2(cs)),
                    B9(gpiob.pb4.into_alternate_af1(cs)),
                    B10(gpiob.pb5.into_alternate_af1(cs)),
                    B11(gpiob.pb6.into_alternate_af2(cs)),
                    B12(gpiob.pb7.into_alternate_af2(cs)),
                    B13(gpiob.pb8.into_alternate_af2(cs)),
                    B14(gpiob.pb9.into_alternate_af2(cs)),
                ),
            };

            //options: change pin mode at runtime, but this causes issues with the tuple types --- need to overwrite enum in place or erase typestate or something
            //could also impl my own trait on each af pin to enable/disable associated timer channel

            let reporter = reporter::Reporter::new(&usb_bus);

            let usb_device = UsbDeviceBuilder::new(&usb_bus, UsbVidPid(0x16c0, 0x27dd))
                .manufacturer("Keming Labs")
                .product("Touchtron")
                //.serial_number("TEST")
                .build();

            init::LateResources {
                exti,
                leds: (led0, led1),
                usb_device,
                reporter,
                touchpad,
            }
        })
    }

    #[idle(resources = [touchpad])]
    fn idle(mut c: idle::Context) -> ! {
        c.resources.touchpad.lock(|t| {
            t.adc.start(0);
        });

        loop {
            wfi();
        }
    }

    #[task(binds = ADC_COMP, priority = 3, resources = [touchpad, reporter])]
    fn handle_adc(mut c: handle_adc::Context) {
        if let Some(latest_reading) = c.resources.touchpad.adc_interrupt() {
            match c.resources.reporter.queued {
                Some(ref mut data) => {
                    data.add(&latest_reading);
                }
                None => {
                    c.resources.reporter.queue(latest_reading);
                }
            }
        }
    }

    #[task(binds = USB, priority = 3, resources = [usb_device, reporter])]
    fn usb(c: usb::Context) {
        // let usb = unsafe { &(*hw::USB::ptr()) };
        // let status = usb.istr.read();
        // if status.susp().is_suspend() {}
        // cortex_m_semihosting::hprintln!("usb interrupt: {:#018b}", status.bits()).unwrap();
        //0b0000 1001 0000 0000
        //cortex_m_semihosting::hprintln!("usb");

        c.resources.usb_device.poll(&mut [c.resources.reporter]);
        //TODO: not clear from the docs whether I need to call poll myself here: https://docs.rs/usb-device/0.2.5/usb_device/device/index.html
        //if I do, then usb only works for a few heatmap frames --- maybe I get stuck in the interrupt handler due to the reporter's recursion?
        // use usb_device::class_prelude::*;
        // c.resources.reporter.poll();
    }
};

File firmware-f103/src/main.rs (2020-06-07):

#![no_std]
#![no_main]

extern crate panic_semihosting;

mod counter;
mod reporter;

use embedded_hal::digital::v2::{InputPin, OutputPin};
use stm32_usbd::UsbBus;
use stm32f1xx_hal::stm32 as hw;
use stm32f1xx_hal::{gpio, prelude::*, usb, usb::UsbBusType};
use usb_device::prelude::*;

use rtfm::app;

const N: usize = 12;
const M: usize = 2;

pub struct TouchData {
    pub inner: [u16; N * M],
}

impl TouchData {
    fn new() -> TouchData {
        TouchData {
            inner: [1u16; M * N],
        }
    }
}

//TODO: is this the best way to get array of u16 into a slice of u8?
impl AsRef<[u8]> for TouchData {
    #[inline]
    fn as_ref(&self) -> &[u8] {
        unsafe {
            core::slice::from_raw_parts_mut(self.inner.as_ptr() as *mut u8, self.inner.len() * 2)
        }
    }
}

#[app(device = hw)]
const APP: () = {
    struct Resources {
        exti: hw::EXTI,
        counter: counter::Counter<'static, UsbBusType>,
        reporter: reporter::Reporter<'static, UsbBusType, TouchData>,
        midi: usbd_midi::midi_device::MidiClass<'static, UsbBusType>,
        usb_device: UsbDevice<'static, UsbBusType>,
        led: gpio::gpioc::PC13<gpio::Output<gpio::PushPull>>,
        input: gpio::gpiob::PB12<gpio::Input<gpio::PullUp>>,
    }

    // Interrupt handlers used to dispatch software tasks
    extern "C" {
        fn ADC1_2();
    }

    #[init]
    fn init(_cx: init::Context) -> init::LateResources {
        let dp = hw::Peripherals::take().unwrap();
        //Configure button interrupt
        // Enable the alternate function I/O clock (for external interrupts)
        dp.RCC.apb2enr.write(|w| w.afioen().enabled());

        let mut flash = dp.FLASH.constrain();
        let mut rcc = dp.RCC.constrain();

        let clocks = rcc
            .cfgr
            .use_hse(8.mhz())
            .sysclk(48.mhz())
            .pclk1(24.mhz())
            .freeze(&mut flash.acr);

        assert!(clocks.usbclk_valid());

        // Configure the on-board LED (PC13, green)
        let mut gpioc = dp.GPIOC.split(&mut rcc.apb2);
        let mut led = gpioc.pc13.into_push_pull_output(&mut gpioc.crh);
        led.set_low().ok();

        ////////////////
        //Configure button interrupt
        let mut gpiob = dp.GPIOB.split(&mut rcc.apb2);
        let input = gpiob.pb12.into_pull_up_input(&mut gpiob.crh);

        // Set EXTI12 multiplexers to use port B
        dp.AFIO.exticr4.write(|w| unsafe { w.exti12().bits(0x01) });
        // Enable interrupt on EXTI12
        dp.EXTI.imr.write(|w| w.mr12().set_bit());
        // Set falling and rising trigger selection for EXTI12
        dp.EXTI.ftsr.write(|w| w.tr12().set_bit());
        dp.EXTI.rtsr.write(|w| w.tr12().set_bit());

        ////////////////
        //Configure USB
        static mut USB_BUS: Option<usb_device::bus::UsbBusAllocator<UsbBusType>> = None;

        let gpioa = dp.GPIOA.split(&mut rcc.apb2);
        unsafe {
            USB_BUS = Some(UsbBus::new(usb::Peripheral {
                usb: dp.USB,
                pin_dm: gpioa.pa11,
                pin_dp: gpioa.pa12,
            }));

            //this is a hack to workaround rtfm lifetime issues
            let usb_bus = USB_BUS.as_ref().unwrap();

            let counter = counter::Counter::new(usb_bus);
            let reporter = reporter::Reporter::new(usb_bus);
            let midi = usbd_midi::midi_device::MidiClass::new(usb_bus);

            let usb_device = UsbDeviceBuilder::new(usb_bus, UsbVidPid(0x16c0, 0x27dd))
                .manufacturer("Fake company")
                .product("Foo")
                .serial_number("TEST")
                //use usbd_midi::data::usb::constants::USB_CLASS_NONE;
                //        .device_class(USB_CLASS_NONE)
                .build();

            init::LateResources {
                exti: dp.EXTI,
                usb_device,
                counter,
                reporter,
                midi,
                led,
                input,
            }
        }
    }

    #[idle(resources = [usb_device, counter, reporter, midi])]
    fn idle(c: idle::Context) -> ! {
        //generate random touch data
        c.resources.reporter.queue(TouchData::new());

        loop {
            if !c.resources.usb_device.poll(&mut [
                c.resources.counter,
                c.resources.reporter,
                c.resources.midi,
            ]) {
                continue;
            }
        }
    }

    #[task(priority = 2, binds = EXTI15_10, resources = [exti, led, input])]
    fn exti15_10(mut c: exti15_10::Context) {
        //clear interrupt
        c.resources.exti.pr.modify(|_, w| w.pr12().set_bit());

        let led = &mut c.resources.led;
        if c.resources.input.is_high().unwrap() {
            led.set_high().unwrap();
        } else {
            led.set_low().unwrap();
        }
    }
};

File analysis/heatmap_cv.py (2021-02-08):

import cv2
import numpy as np
import matplotlib.pyplot as plt
import matplotlib.animation as animation
import time


####################################

N = 15
M = 10
bytes_to_read = (1 + N * M) * 2 #u16 vals

import usb.core
d = usb.core.find(idVendor=0x16c0, idProduct=0x27dd)
d.set_configuration()

address = 0x81 #this is always the address of first endpoint.

def read_touchpad():
    buffer = d.read(address, bytes_to_read)
    data = np.frombuffer(buffer, dtype = np.dtype(np.uint16))
    num_samples = data[0]
    return (data[1:][::-1].reshape(M,N) / num_samples).astype(np.uint8)

# def read_touchpad():    
#     return cv2.imread("/Users/dev/Desktop/blobs.png", cv2.IMREAD_GRAYSCALE)

Offset = 50

def process(m):
    m = np.maximum(m.astype(np.int16) - Offset, 0)
    m = cv2.pyrUp(m, m.size*8)
    m = cv2.resize(m, (600,400), interpolation=cv2.INTER_NEAREST)
    return m.astype(np.uint8)




params = cv2.SimpleBlobDetector_Params() 
# Change thresholds
params.minThreshold = 80
params.maxThreshold = 255

params.filterByColor = True
params.blobColor = 255

# Filter by Area.
params.filterByArea = True
params.minArea = 10

# Filter by Circularity
params.filterByCircularity = False
params.minCircularity = 0.1

# Filter by Convexity
params.filterByConvexity = False
params.minConvexity = 0.87

# Filter by Inertia
params.filterByInertia = False
params.minInertiaRatio = 0.01

Detector = cv2.SimpleBlobDetector_create(params)

def on_track(_):
    global Detector
    global Offset
    Offset = cv2.getTrackbarPos("Offset", "processed")
    params.minArea = cv2.getTrackbarPos("Min Area", "processed")
    params.minThreshold = cv2.getTrackbarPos("Min Threshold", "processed")
    Detector = cv2.SimpleBlobDetector_create(params)


def createWindow(name):
    cv2.namedWindow(name, cv2.WINDOW_NORMAL)
    cv2.resizeWindow(name, 600,400)


createWindow("raw")
createWindow("processed")
#createWindow("text")
cv2.createTrackbar("Offset", "processed", Offset, 255, on_track)
cv2.createTrackbar("Min Area", "processed", int(params.minArea), 1000, on_track)
cv2.createTrackbar("Min Threshold", "processed", int(params.minThreshold), 255, on_track)




def step():
    m = read_touchpad()
    #cv2.imshow("raw", cv2.applyColorMap(m, cv2.COLORMAP_VIRIDIS))
    cv2.imshow("raw", m)
    m = process(m)
    keypoints = Detector.detect(m)
    m = cv2.applyColorMap(m, cv2.COLORMAP_VIRIDIS)

    #m = cv2.drawKeypoints(m, keypoints, np.array([]), (0,0,255), cv2.DRAW_MATCHES_FLAGS_NOT_DRAW_SINGLE_POINTS)
    for k in keypoints:
        m = cv2.circle(m, (int(k.pt[0]), int(k.pt[1])), 8, (0, 0, 255), -1)
    #m = cv2.drawKeypoints(m, keypoints, np.array([]), (0,0,255), cv2.DRAW_MATCHES_FLAGS_DRAW_RICH_KEYPOINTS)
    cv2.imshow("processed", m)

    # Render debug info
    # text = np.zeros((300,600), dtype=np.uint8)
    # margin_left = 5
    # margin_top = 30
    # line_height = 30
    # color = (255,255,255)
    # for idx, k in enumerate(keypoints):
    #     cv2.putText(text, f"({int(k.pt[0])}, {int(k.pt[1])}) {int(k.size)}", (margin_left, margin_top + idx*line_height), cv2.FONT_HERSHEY_PLAIN, 1, color)

    # cv2.imshow("text", text)




while(True):
    try:
        step()
    except Exception as e:
        print(e)
    if cv2.waitKey(20) & 0xFF == ord('q'):
        break

#cv2.destroyAllWindows()
exit(0)

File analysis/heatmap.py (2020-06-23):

import numpy as np
import matplotlib.pyplot as plt
import matplotlib.animation as animation
import time
import matplotlib
#matplotlib.use("Qt5Agg")
matplotlib.use("MACOSX")

# import pyqtgraph.examples
# pyqtgraph.examples.run()

n = 15
m = 10
bytes_to_read = (1 + n * m) * 2 #u16 vals

frames_to_read = 1000

####################################

import usb.core
d = usb.core.find(idVendor=0x16c0, idProduct=0x27dd)
d.set_configuration()

address = 0x81 #this is always the address of first endpoint.

def read_touchpad():
    buffer = d.read(address, bytes_to_read)
    data = np.frombuffer(buffer, dtype = np.dtype(np.uint16))
    return data


#########################

fig = plt.figure()
ax = fig.add_subplot()
plot = ax.imshow(np.random.rand(m,n),
                 vmin=0,
                 #vmax=4095, #ADC is actually 12bit only
                 vmax=100,
                 interpolation="nearest",
                 cmap="viridis")


frame_num = 0
frames = np.zeros((frames_to_read, int(bytes_to_read/2)), dtype = np.uint16)

from scipy import signal
from scipy.ndimage import gaussian_filter

def process1(m):
    return gaussian_filter(np.maximum(m - 60, 0), 0.01)

def process1(m):
    return signal.convolve2d(np.maximum(m - 60, 0), np.ones((2,2)) / 4)

    
def animate(i):
    global frame_num
    start = time.time()
    try:
        data = read_touchpad();

        frames[frame_num] = data;
        frame_num += 1

        if frame_num == frames_to_read:
            with open("frames.npy", "wb") as f:
                np.save(f, frames)
            print("Read %s frames, quitting" % frames_to_read)
            exit(0)

        num_samples = data[0]
        # the [::-1] reverses data so we display in same orientation as physical touchpad
        matrix = data[1:][::-1].reshape(m,n) / num_samples
        #print(num_samples, np.amax(matrix))
        plot.set_data(process1(matrix))
        time_taken = time.time() - start
        print(1. / time_taken)
    except Exception as e:
        #yolo
        print(e)
        return None

ani = animation.FuncAnimation(fig, animate, fargs=(), interval=16)

plt.show()


# start = time.time()
# for idx in range(150):
#     read_touchpad();
# print(time.time() - start)

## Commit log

2020-06-04 changes for stm32 discovery board
2020-06-04 WIP: midi controller on blue pill; Allllmost have working button interrupt.
2020-06-05 rtfm-ify stm32f0xx version
2020-06-06 user button toggles led for discovery board
2020-06-06 Interrupt to toggle led working.
2020-06-07 Reorganize to be clearer about the 3 boards we have in play: f0 discovery, f103 blue pill, and f0 touchtron.
2020-06-08 Get USB data reporting working on touchtron board.
2020-06-08 Read ADC successfully.
2020-06-09 WIP: ADC.
2020-06-09 Plot ADC heatmap measuring 3 pins, channels always on. 160--190 FPS.
2020-06-10 WIP: Scan columns; report over USB.
    Running into some kind of USB timeout issue; I don't think the interrupts are setup properly.
    [main.rs]
2020-06-19 WIP: scan PWM periods, report over USB (untested)
2020-06-19 WIP: very low capacitive touch signal, seems quite noisy.
    Even when physically connecting pins, a few frames are displayed full of noise.
    But that doesn't make sense; must be a logic error somewhere.
    [heatmap.py, main.rs]
2020-06-20 More USB experiments. Think I need to just write ADC sampling code myself to average signal over time.
2020-06-21 Continuous scanning of ADC (untested).
2020-06-22 Can't use continous mode because we can't service interrupts fast enough (contention w/ USB interrupt).
    Instead, chain row sampling together in the interrupt.
2020-06-24 OpenCV blob detection for rough finger location detection.
2021-02-08 Add PCB-related files.
    [bom.csv, centroid.csv, touchtron.kicad_pcb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]
2021-02-08 Add schematic PDF.
